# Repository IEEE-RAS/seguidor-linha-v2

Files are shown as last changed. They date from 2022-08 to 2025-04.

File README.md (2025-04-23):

# seguidor-linha-v2
Nova implementação de robo seguidor de linha, versão mais leve e esbelta.

### Sobre a versão 2
O objetivo de uma segunda implementação é expandir o processo de desenvolvimento do robô com etapas de simulação e de uso de tecnologias agora acessíveis, nesse caso, impressão 3D.\
Além do processo, esse robô pode servir como uma base para o desenvolvimento de outros robôs similares em estrutura e funcionamento, diminuindo o esforço do início de um projeto.

## Uso
Este robô possui um adaptador bluetooth para controle e comunicação.\
O nome configurado é `SEGLIN2`, mas o módulo permite configuração via comandos AT quando não conectado.\
Ao ligar o sistema, o robô espera uma conexão com um terminal bluetooth e depende dos comandos para funcionar:
```bash
# Iniciar a peseguição da linha
CM+START

# Parar a perseguição da linha
CM+STOP
```

## Hardware
- DAGU MicroMagician
- TP4056 BMS
- MT3608 step-down
- N20 micro motor
- HC-06 módulo Bluetooth\

\
\
A placa principal escolhida é a **DAGU MicroMagician**, uma placa compacta, compatível com Arduino e que já contém um módulo de controle de motor, receptor de infravermelho e acelerômetro, além de disposição
para servos.\
Para gestão de energia, um BMS (TP4056) para uma célula 18560 e um step-up MT3608.\
Dois motores com redução do tipo N20.\
O módulo utilizado é o HC-06, ou seja, a comunicação AT só é possível enquanto nenhuma conexão com outro dispositivo é estabelecida.
\
\
## Snapshot

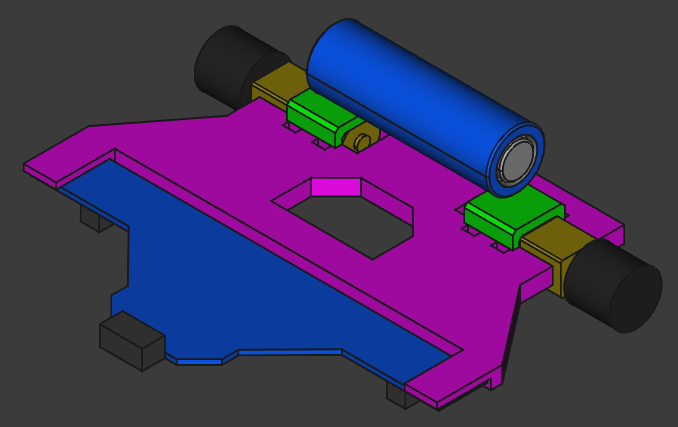
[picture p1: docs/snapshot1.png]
estrutura principal do seguidor v2


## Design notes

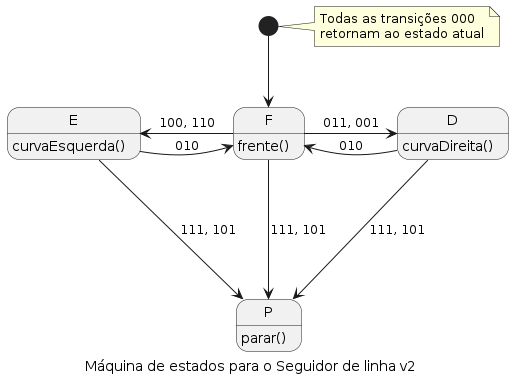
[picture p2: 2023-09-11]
docs/SEGLIN2-FSM/SEGLIN2-FSM.png

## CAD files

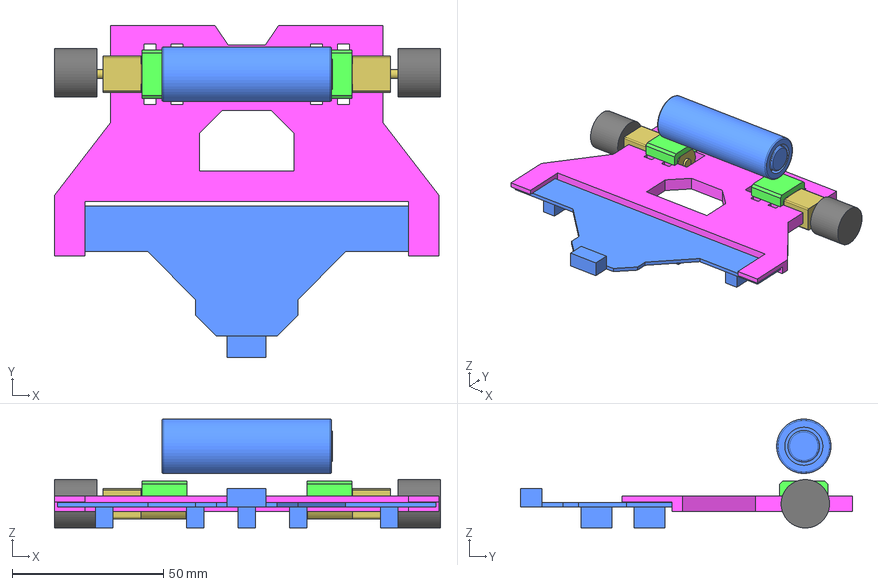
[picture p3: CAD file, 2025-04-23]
models/chassis_rec.FCStd
127.5 x 109.5 x 36.0 mm
motor_support001
motor002
roda1
roda2
bateria001
sensor001
motor001
motor_support002
chassis

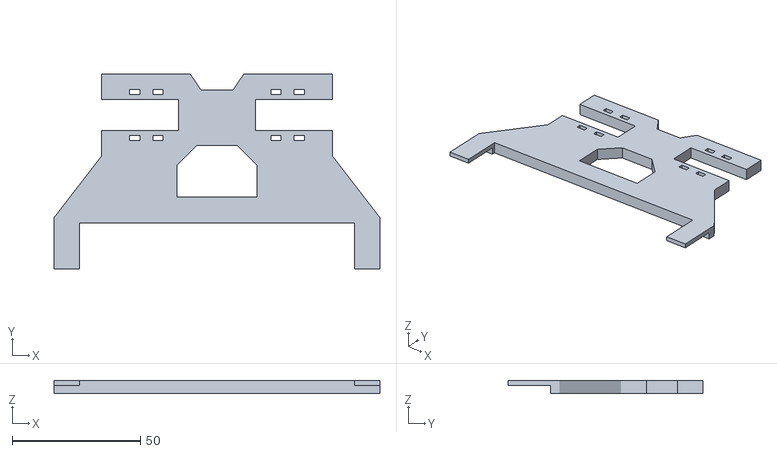
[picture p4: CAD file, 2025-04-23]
models/webots/rearAx-testbed001.stl
127.0 x 76.0 x 5.00

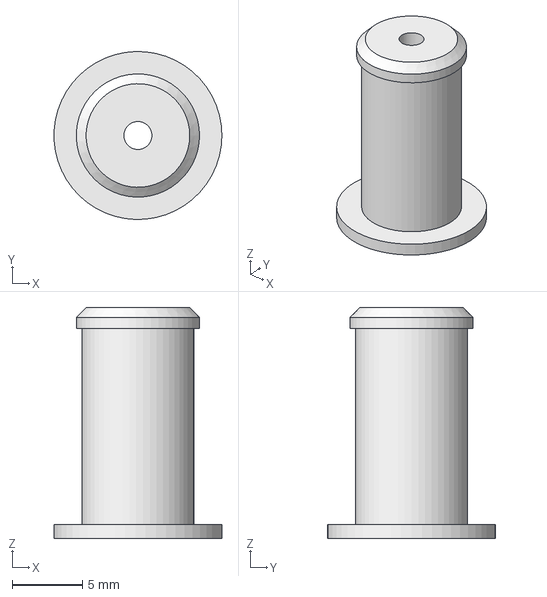
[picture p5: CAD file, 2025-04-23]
models/hubRoda.FCStd
12.0 x 12.0 x 16.5 mm

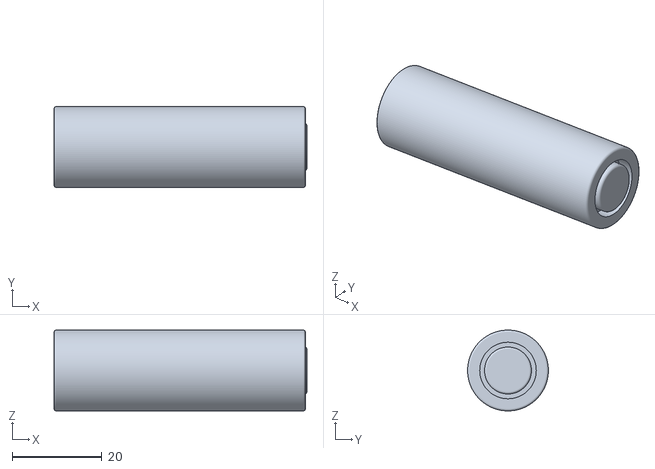
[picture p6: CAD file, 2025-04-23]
models/webots/rearAx-bateria001.stl
56.3 x 18.0 x 18.0

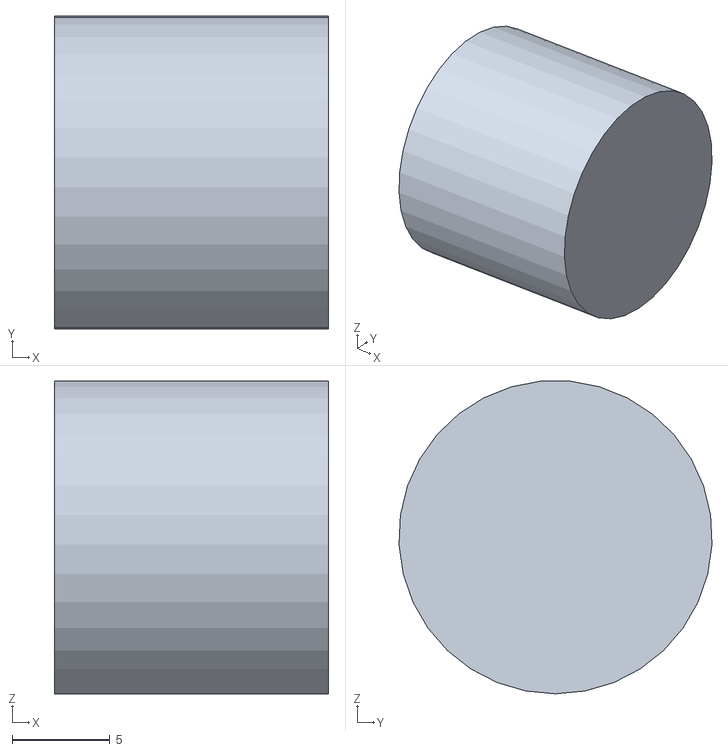
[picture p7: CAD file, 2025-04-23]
models/webots/rearAx-roda1.stl
14.0 x 16.0 x 16.0

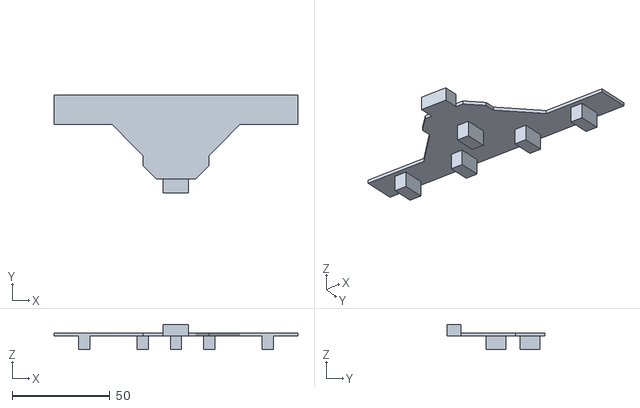
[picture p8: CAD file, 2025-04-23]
models/webots/rearAx-sensor001.stl
125.0 x 50.0 x 13.0

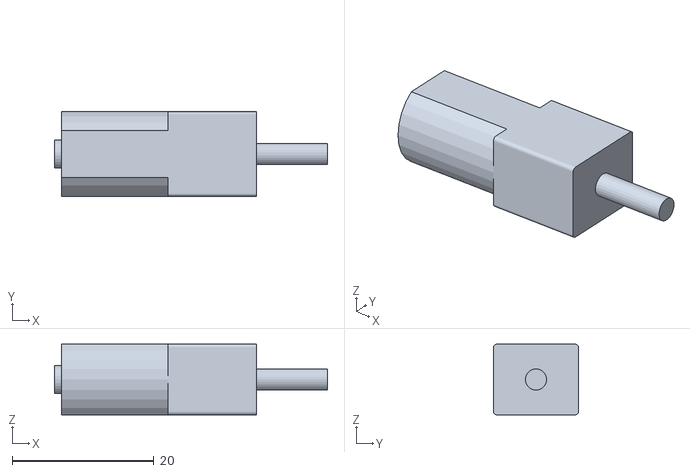
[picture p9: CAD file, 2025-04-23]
models/webots/rearAx-motor001.stl
38.5 x 12.0 x 10.0

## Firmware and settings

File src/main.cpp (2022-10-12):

#include <Arduino.h>
#include <microM.h>
#include <SoftwareSerial.h>
// #define __DEBUG__

/**
 * @brief Pinos de controle dos motores, os pinos foram escolhidos por
 * terem capacidade de realizar PWM, para controle de velocidade.
 * São nomeados de acordo com as entradas do módulo de ponte H utilizado
 *
 */
#define A1A 8
#define A1B 7
#define B1A 5
#define B1B 6

/**
 * @brief Pinos dos sensores de linha, começando com o sensor mais à esquerda
 * (SEE) passando pelo sensor ao centro (SC) até o sensor mais à direita (SDD)
 *
 */
#define SEE 9
#define SES 10
#define SC 11
#define SD 12
#define SDD 13

/**
 * @brief Definição auxiliar para sentido de rotação
 *
 */
#define CW 1  // Horário
#define CCW 0 // Anti-horário

#define MAX_PWM 100
#define RED_FATOR 0.25

/**
 * @brief Constantes de comunicação Bluetooth
 *
 */
#define BTRX 2
#define BTTX 3
// #define BTKEY 4
#define BTBAUD 9600

/**
 * @brief Estrutura de motor: Contém os pinos do motor e o sentido
 * de rotação para direção à frente
 *
 */
struct motor
{
  byte TA, TB;
  bool dir;
};

struct motor MotE = {A1A, A1B, CW}, MotD = {B1A, B1B, CCW};

SoftwareSerial btSerial(BTRX, BTTX);
String command = "";
bool togKey = LOW;

char cmdChar = ' ';
char cmdFlag = false;

/**
 * @brief Para os motores levando todos os pinos de motores para LOW
 *
 */
void stop()
{
  digitalWrite(MotE.TA, LOW);
  digitalWrite(MotE.TB, LOW);
  digitalWrite(MotD.TA, LOW);
  digitalWrite(MotD.TB, LOW);
}

/**
 * @brief Função de aceleração dos motores
 *
 * @param from valor inicial do PWM
 * @param to valor final do PWM
 * @param rate taxa de adição do valor de PWM
 */
void accelerate(int from, int to, int rate)
{
  for (int i = from; i < to; i += rate)
  {
    // rotateAnalog(MotE.dir, MotE, i);
    // rotateAnalog(MotD.dir, MotD, i);
    microM.Motors(i, i, 0, 0);
    delay(5);
  }
}

/**
 * @brief Seguir em frente: ativa os motores com a velocidade máxima para frente
 *
 * @param accel ativa ou desativa pequena aceleração para reduzir corrente
 */
void forward(bool accel = true)
{
  if (accel)
  {
    accelerate(30, MAX_PWM, 2);
  }

  // rotateAnalog(MotE.dir, MotE, 255);
  // rotateAnalog(MotD.dir, MotD, 255);
  microM.Motors(MAX_PWM, MAX_PWM, 0, 0);

#ifdef __DEBUG__
  Serial.println("em frente");
#endif
}

/**
 * @brief Vira a direita: Reduz velocidade do motor direito para provocar curva à direita
 *
 */
void turnRight()
{

  // rotateAnalog(MotE.dir, MotE, MAX_PWM);
  // rotateAnalog(MotD.dir, MotD, MAX_PWM * RED_FATOR);
  microM.Motors(MAX_PWM, MAX_PWM * RED_FATOR, 0, 0);

#ifdef __DEBUG__
  Serial.println("D");
#endif
}

/**
 * @brief Vira à esquerda: Reduz velocidade do motor ESQUERDO para provocar curva à esquerda
 *
 */
void turnLeft()
{
  // rotateAnalog(MotE.dir, MotE, MAX_PWM * RED_FATOR);
  // rotateAnalog(MotD.dir, MotD, MAX_PWM);
  microM.Motors(MAX_PWM * RED_FATOR, MAX_PWM, 0, 0);

#ifdef __DEBUG__
  Serial.println("E");
#endif
}

void setup()
{
  pinMode(LED_BUILTIN, OUTPUT);

  pinMode(MotE.TA, OUTPUT);
  pinMode(MotE.TB, OUTPUT);
  pinMode(MotD.TA, OUTPUT);
  pinMode(MotD.TB, OUTPUT);

  // pinMode(BTKEY, OUTPUT);
  // digitalWrite(BTKEY, LOW);
  btSerial.begin(BTBAUD);
  btSerial.write("SEGLIN v2 BT\n");

#ifdef __DEBUG__
  Serial.begin(9600);
#endif
  // forward();
}

/**
 * @brief Matrizes de estados de sensores, atuais e antigos
 *
 */
bool state[5] = {0, 0, 0, 0, 0}, oldState[5];

/**
 * @brief Matriz de pinos de sensores IR
 *
 */
int dsarr[5] = {SEE, SES, SC, SD, SDD};

/**
 * @brief Flags de desvio e estados individuais.
 *
 */
int stateOut = 0, stateOutOld = 0, detourCount = 0;
bool takeDetour = 0;

/**
 * @brief Flag de estado automato
 *
 */
bool autoState = 0;

/**
 * @brief Atualiza os estados da matriz state e salva os estados antigos na matriz
 * oldState a partir dos valores lidos na matriz de pinos de sensores ds
 *
 * @param ds matriz com os pinos dos sensors IR
 * @param nds numero de sensores na matriz ds
 * @param oldState matriz de estados de sensor salvos da iteração anterior
 * @param state matriz que deverá conter os últimos estados de sensor lidos
 * @param ns numero de estados de sensor
 */
void updateStates(int ds[], int nds, bool oldState[], bool state[], int ns)
{

  for (int i = 0; i < ns; i++)
  {
    oldState[i] = state[i];
  }

  for (int d = 0; d < nds; d++)
  {
    state[d] = !digitalRead(ds[d]);
  }
}

/**
 * @brief Concatena os bits dos estados de sensores
 * em um unico byte representando o estado de maquina
 *
 * @param stateOut estado de saída
 * @param state matriz com os estados a serem concatenados
 */
void concatStates(int &stateOut, bool state[])
{
  stateOut = stateOut | (state[1] << 2);
  stateOut = stateOut | (state[2] << 1);
  stateOut = stateOut | state[3];
}

void loop()
{

  stateOut = 0;

  updateStates(dsarr, 5, oldState, state, 5);

  /**
   * @brief Concatena os bits dos estados de sensores
   * em um unico byte representando o estado de maquina
   *
   */
  concatStates(stateOut, state);

  /**
   * @brief Executa a avaliação principal dos estados da máquina de estados
   *
   */
  if (autoState)
  {
    if (stateOut != stateOutOld)
    {
      stateOutOld = stateOut;
      switch (stateOut)
      {
      case 2:
        forward(false);
        break;
      case 1:
      case 3:
        turnRight();
        break;
      case 6:
      case 4:
        turnLeft();
        break;
      case 7:
        stop();
      default:
        break;
      }
    }
  }

  if (btSerial.available())
  {
    while (btSerial.available())
    {
      cmdChar = (char)btSerial.read();
      command += cmdChar;
      if (command.compareTo("CM+") == 0)
      {
        command = "";
        cmdFlag = true;
      }
    }
    if (cmdFlag)
    {
      cmdFlag = false;
      if (command.compareTo("START\r\n") == 0)
      {
        forward();
        autoState = true;
      }
      if (command.compareTo("STOP\r\n") == 0)
      {
        stop();
        autoState = false;
      }
      btSerial.write("OK");
    }
    command = "";
    btSerial.write("\r\n");
  }

  delay(5);
}

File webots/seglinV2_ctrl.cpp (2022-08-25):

// File:          seglinV2_ctrl.cpp
// Date:
// Description:
// Author:
// Modifications:

#include <webots/Robot.hpp>
#include <webots/Motor.hpp>
#include <webots/DistanceSensor.hpp>
#include <webots/LED.hpp>

#define MAX_SPEED 10
#define REDUCTION_FACTOR 0.25

#define MIN_THRESHOLD 15
#define MAX_THRESHOLD 70

using namespace webots;

bool readSensorBinaryState(DistanceSensor *ds)
{
    double reading = ds->getValue();
    if ((MIN_THRESHOLD < reading) && (reading < MAX_THRESHOLD))
    {
        return true;
    }

    return false;
}

void stateLED(LED *led, bool oldState, bool state)
{
    if (state != oldState)
        led->set(state);
}

void updateStates(DistanceSensor *ds[], int nds, bool (&oldState)[], bool (&state)[], int ns)
{

    for (int i = 0; i < ns; i++)
    {
        oldState[i] = state[i];
    }

    for (int d = 0; d < nds; d++)
    {
        state[d] = readSensorBinaryState(ds[d]);
    }
}

void curvaAoCentro(DistanceSensor *ds, DistanceSensor *dc, LED *led, Motor *ME, Motor *MD, void (*funcao)(Motor *, Motor *))
{
    double reading = ds->getValue();

    if ((MIN_THRESHOLD < reading) && (reading < MAX_THRESHOLD))
    {
        funcao(ME, MD);
        led->set(1);
        printf("curva");
    }
}

void curvaAoCentro(bool oldState, bool state, Motor *ME, Motor *MD, void (*funcao)(Motor *, Motor *))
{
    if (state != oldState)
    {
        if (state)
            funcao(ME, MD);
    }
}

void turnLeft(Motor *ME, Motor *MD)
{
    printf("Left\n");
    ME->setVelocity(MAX_SPEED * REDUCTION_FACTOR);
    MD->setVelocity(MAX_SPEED);
}

void turnRight(Motor *ME, Motor *MD)
{
    printf("Right\n");
    MD->setVelocity(MAX_SPEED * REDUCTION_FACTOR);
    ME->setVelocity(MAX_SPEED);
}

void stop(Motor *ME, Motor *MD)
{
    ME->setVelocity(0);
    MD->setVelocity(0);
}

void forward(Motor *ME, Motor *MD)
{
    printf("forward\n");
    ME->setVelocity(MAX_SPEED);
    MD->setVelocity(MAX_SPEED);
}

int main(int argc, char **argv)
{
    // create the Robot instance.
    Robot *robot = new Robot();

    // get the time step of the current world.
    int timeStep = (int)robot->getBasicTimeStep();

    Motor *md = robot->getMotor("md");
    Motor *me = robot->getMotor("me");

    md->setPosition(INFINITY);
    md->setVelocity(MAX_SPEED);
    me->setPosition(INFINITY);
    me->setVelocity(MAX_SPEED);

    DistanceSensor *dsc = robot->getDistanceSensor("dsc");
    dsc->enable(timeStep);
    DistanceSensor *dsei = robot->getDistanceSensor("dsei");
    dsei->enable(timeStep);
    DistanceSensor *dsee = robot->getDistanceSensor("dsee");
    dsee->enable(timeStep);
    DistanceSensor *dsdi = robot->getDistanceSensor("dsdi");
    dsdi->enable(timeStep);
    DistanceSensor *dsde = robot->getDistanceSensor("dsde");
    dsde->enable(timeStep);

    DistanceSensor *dsarr[5] = {dsee, dsei, dsc, dsdi, dsde};

    LED *sled1 = robot->getLED("sled1");
    sled1->set(0);
    LED *sled0 = robot->getLED("sled0");
    sled0->set(0);
    LED *sled2 = robot->getLED("sled2");
    sled2->set(0);
    LED *sled3 = robot->getLED("sled3");
    sled2->set(0);
    LED *sled4 = robot->getLED("sled4");
    sled2->set(0);

    LED *led[5] = {sled3, sled2, sled0, sled1, sled4};

    bool state[5] = {0, 0, 0, 0, 0}, oldState[5];

    double startT = 0, finishT = 0;

    int stateOut = 0, stateOutOld = 0, detourCount = 0;
    bool takeDetour = 0;

    while (robot->step(timeStep) != -1)
    {

        stateOut = 0;

        updateStates(dsarr, 5, oldState, state, 5);

        stateOut = stateOut | (state[1] << 2);
        stateOut = stateOut | (state[2] << 1);
        stateOut = stateOut | state[3];

        for (int s = 0; s < 5; s++)
        {
            stateLED(led[s], oldState[s], state[s]);
        }

        if (state[0] != oldState[0])
            if (state[0] && state[4])
            {
                printf("code1\n");
                // takeDetour = !takeDetour;
                detourCount++;
                printf("detourCount %d\n", detourCount);
            }

        if (detourCount == 2)
            takeDetour = !takeDetour;

        if (stateOut != stateOutOld)
        {
            printf("%d\n", stateOut);
            stateOutOld = stateOut;
            switch (stateOut)
            {
            case 2:
                forward(me, md);
                break;
            case 1:
            case 3:
                if (!takeDetour)
                    turnRight(me, md);
                break;
            case 6:
            case 4:
                if (!takeDetour)
                    turnLeft(me, md);
                break;
            case 7:
                stop(me, md);
            default:
                break;
            }
        }
    };

    delete robot;
    return 0;
}

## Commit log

2022-05-24 comandos de direção + refatoraçao
2022-06-01 add accel limit current
2022-06-06 sensores de desvio da linha
2022-06-08 refator pra pwm maximo
2022-08-25 ajuste de velocidade
2022-08-25 Refatoração para maquina de estados
2022-09-08 mudança de placa MicroMagician
2022-10-09 limpeza de funções desnecessárias
2022-10-09 bug: ignora as curvas
    [main.cpp]
2022-10-09 eliminação de condição de desvio
2022-10-09 config serial para comunicação com BT
2022-10-10 interpretação de comando via bt (testes)
2023-09-11 diagrama de estados
2025-04-23 Modelos para simulador webots
    [rearAx-bateria001.stl, rearAx-motor001.stl, rearAx-roda1.stl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]
2025-04-23 modelos estrutura
    [chassis_rec.FCStd, hubRoda.FCStd]
